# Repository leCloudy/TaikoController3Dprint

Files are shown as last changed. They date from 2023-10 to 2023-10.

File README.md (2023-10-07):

# TaikoController3Dprint
3D printed taiko controller Arduino based for PC. 

I started on this project as taiko drum controllers are expensive (~$100+) and this project costed me less than 10$ (I already have some tools).

If possible I would recommend to make this using wood as it can be scaled bigger.
### 3D Model





Modelled in Fusion360. I provided the f3d files and the STL files if you want to edit them.

### Controller


#### Circuit




I ended up attaching the piezo using blutack to the centre of the back of the don and ka plates

### Printing instructions


As the piezo are used to detect vibration, using a 100% infill should help but it worked for me using 40%.
This was printed using an modded ender3v2. The dimensions are maxed for the print bed, but if you have a bigger printer you can scale it up.
Print the standoff with 0% infill to reduce the transmission of vibration. If possible it can be substituted with something soft like a silicon sock.

### Items
1) Arduino Micro
2) M5x25 with M5 nuts (x12)
3) 10mm Piezo Ceramic Wafer (x4)

### Code
Referenced from: https://github.com/LuiCat/ArduinoTaikoController/tree/master
Calibration needs to be accurate as the other piezos might false trigger.

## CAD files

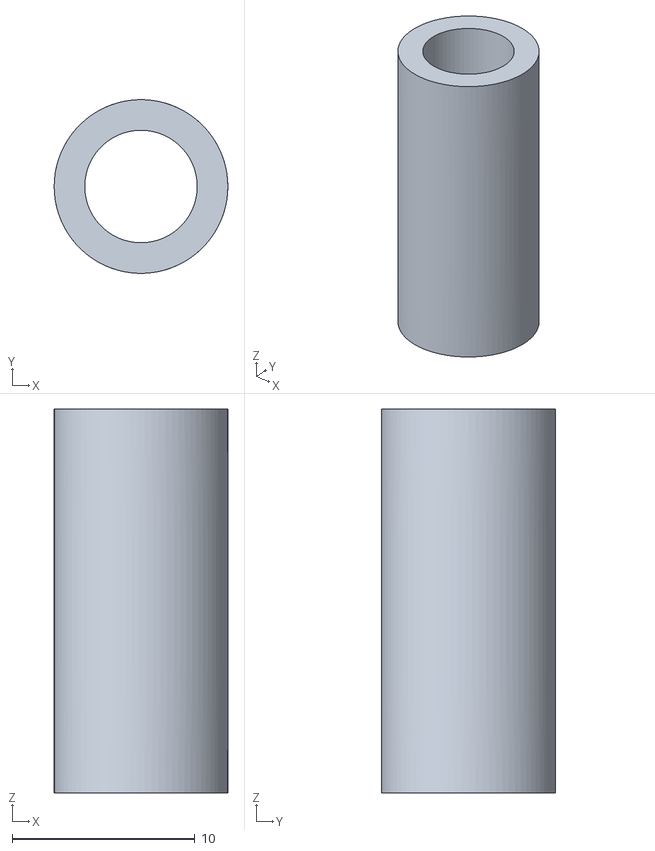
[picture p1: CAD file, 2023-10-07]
standoff.stl
9.50 x 9.50 x 21.0

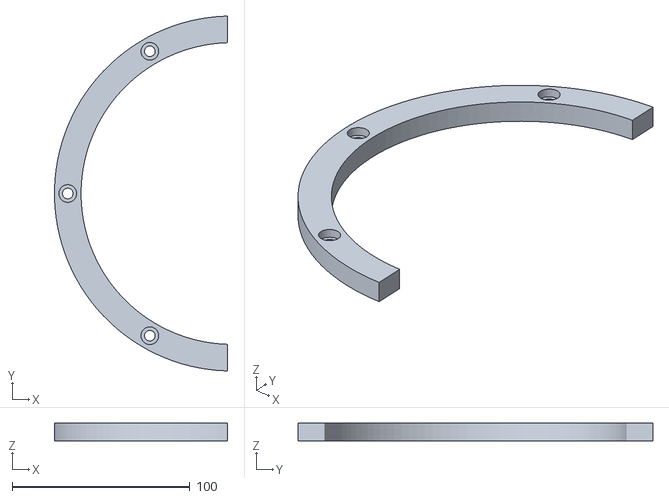
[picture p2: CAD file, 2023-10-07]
ka.stl
97.5 x 199.9 x 10.0

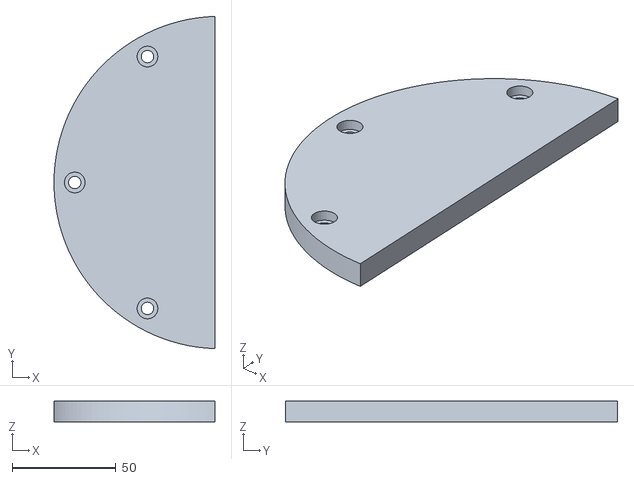
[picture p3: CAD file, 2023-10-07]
don.stl
77.5 x 159.9 x 10.0

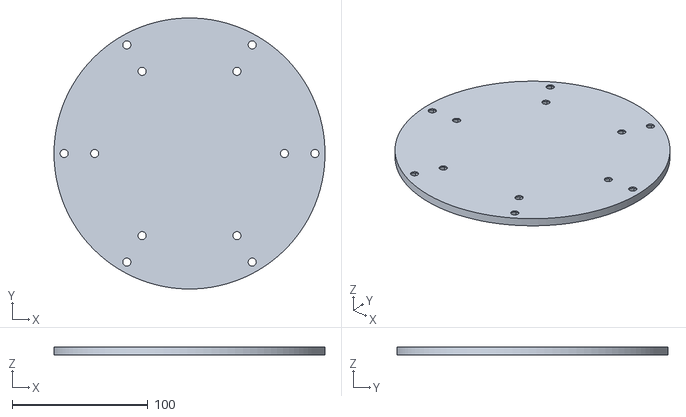
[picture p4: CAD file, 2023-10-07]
backplate.stl
200.0 x 200.0 x 6.00

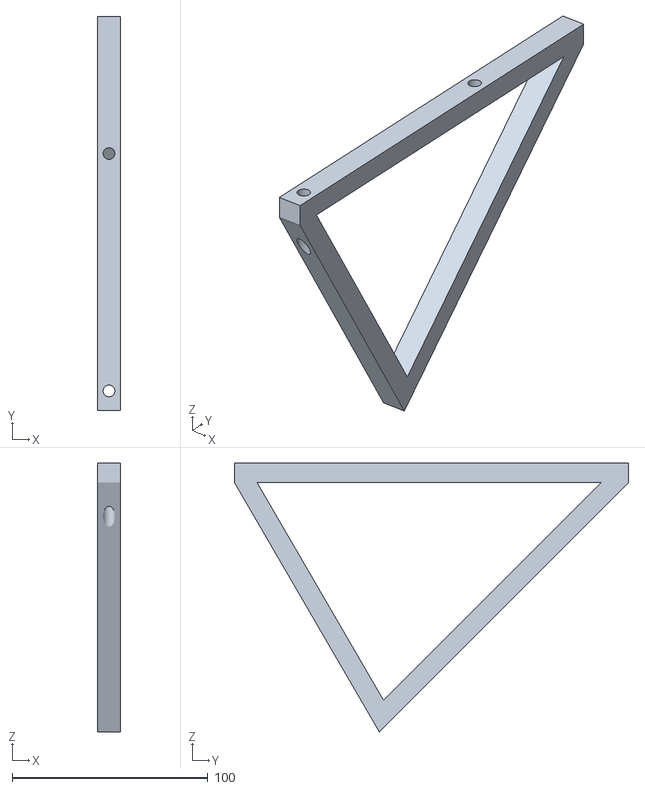
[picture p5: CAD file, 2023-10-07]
stand.stl
11.5 x 201.2 x 137.3

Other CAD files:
taiko v7.f3d
